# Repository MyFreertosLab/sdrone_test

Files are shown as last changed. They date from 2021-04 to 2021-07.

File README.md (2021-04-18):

ESP32 ESP-IDF Drone
===================

This is a Drone Test Implementation with esp-idf and esp32.
This software is under construction

```
  git clone --recursive git@github.com:MyFreertosLab/sdrone_test.git
  idf.py build
  idf.py flash
```
<h1>State of the art</h1>
<p align="left">
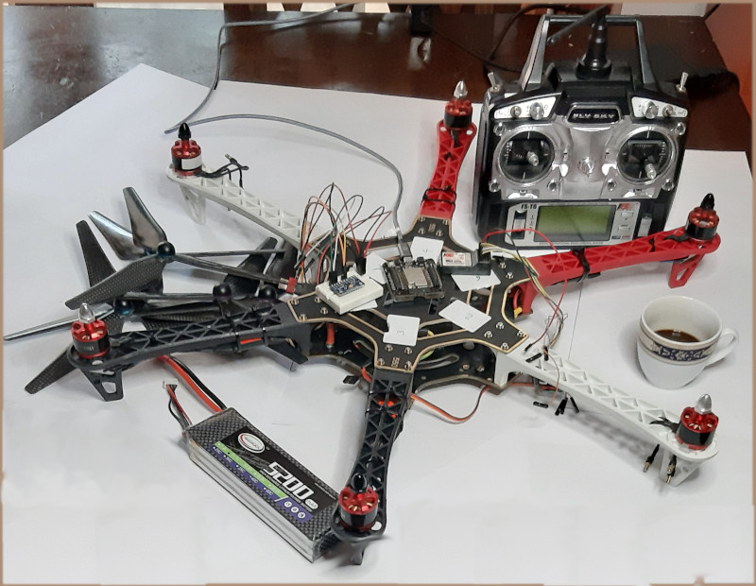
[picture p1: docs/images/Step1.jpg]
The hardware
  
  <p>Step 1: Minimal Hardware List</p>
</p>

1) The frame
2) RC TX/RX
3) PPM Encoder
4) IMU (mpu9250) with at least accelerometer and gyroscope
5) Battery
6) Esc (30Ah)
7) Motors
8) Propellers
9) The Board (a simple ESP32 board)
10) Cup of coffee

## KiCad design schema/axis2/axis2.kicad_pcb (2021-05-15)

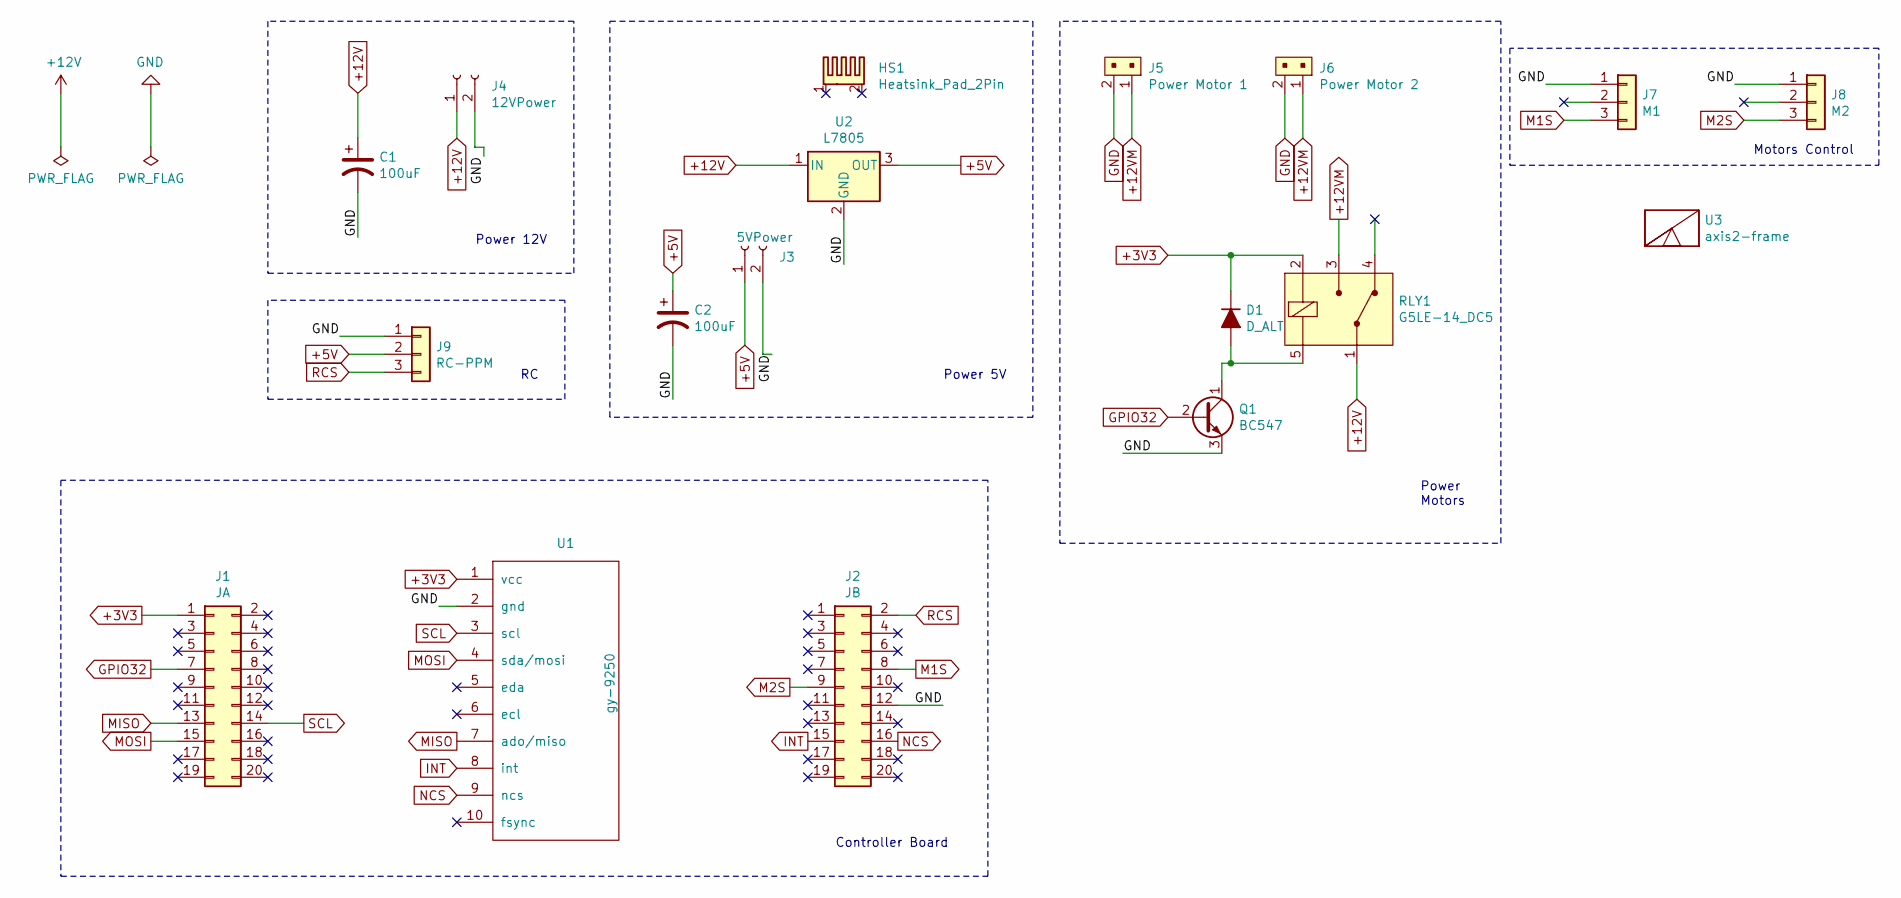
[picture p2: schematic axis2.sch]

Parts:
C1, C2: 100uF; CP_Radial_D5.0mm_P2.50mm
D1: D_ALT; D_DO-34_SOD68_P7.62mm_Horizontal
HS1: Heatsink_Pad_2Pin; Heatsink_Stonecold_HS-132_32x14mm_2xFixation1.5mm
J1: JA; PinSocket_2x10_P2.54mm_Vertical
J2: JB; PinSocket_2x10_P2.54mm_Vertical
J3: 5VPower; JST_XH_B2B-XH-AM_1x02_P2.50mm_Vertical
J4: 12VPower; BarrelJack_Wuerth_6941xx301002
J5: Power Motor 1; Deans; MPN 22-23-2021; Digi-Key_PN WM4200-ND
J6: Power Motor 2; Deans; MPN 22-23-2021; Digi-Key_PN WM4200-ND
J7: M1; PinHeader_1x03_P2.54mm_Horizontal
J8: M2; PinHeader_1x03_P2.54mm_Horizontal
J9: RC-PPM; PinHeader_1x03_P2.54mm_Horizontal
Q1: BC547; TO-92
RLY1: G5LE-14_DC5; Relay_SPDT_Omron-G5LE-1; MPN G5LE-14 DC5; Digi-Key_PN Z1011-ND
U1: gy-9250
U2: L7805; TO-220-3_Vertical
U3: axis2-frame; axis2-footprint

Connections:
+3V3: D1.1 (K), J1.1, RLY1.2 (COIL), U1.1 (vcc)
+5V: C2.1, J3.1, J9.2, U2.3 (OUT)
+12V: C1.1, J4.1, RLY1.1 (COM), U2.1 (IN)
+12VM: J5.1, J6.1, RLY1.3 (NO)
GND: C1.2, C2.2, J2.12, J3.2, J4.2, J5.2, J6.2, J7.1, J8.1, J9.1, Q1.3 (E), U1.2 (gnd), U2.2 (GND)
GPIO32: J1.7, Q1.2 (B)
INT: J2.15, U1.8 (int)
M1S: J2.8, J7.3
M2S: J2.9, J8.3
MISO: J1.13, U1.7 (ado/miso)
MOSI: J1.15, U1.4 (sda/mosi)
NCS: J2.16, U1.9 (ncs)
unnamed: D1.2 (A), Q1.1 (C), RLY1.5 (COIL)
RCS: J2.2, J9.3
SCL: J1.14, U1.3 (scl)

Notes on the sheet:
Power Motors
Power 12V
Power 5V
Controller Board
Motors Control

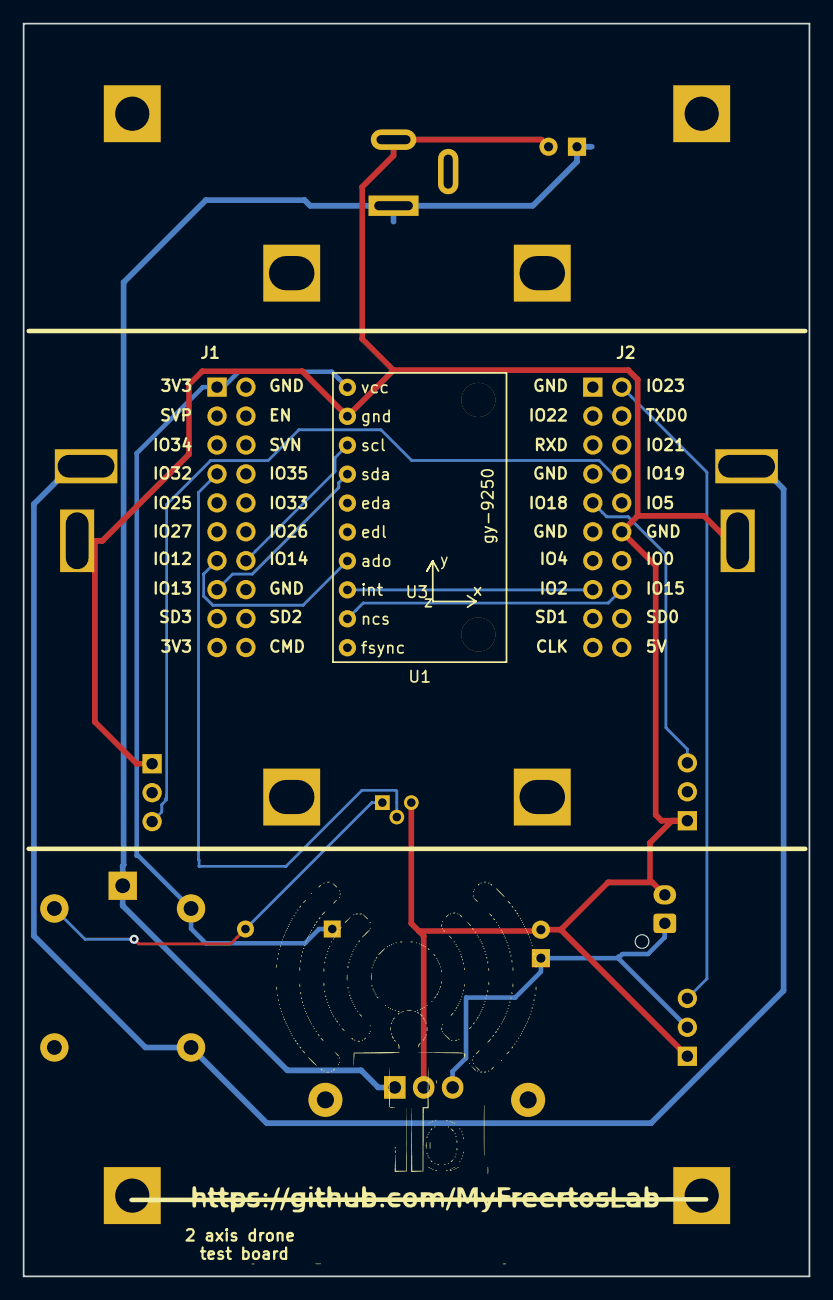
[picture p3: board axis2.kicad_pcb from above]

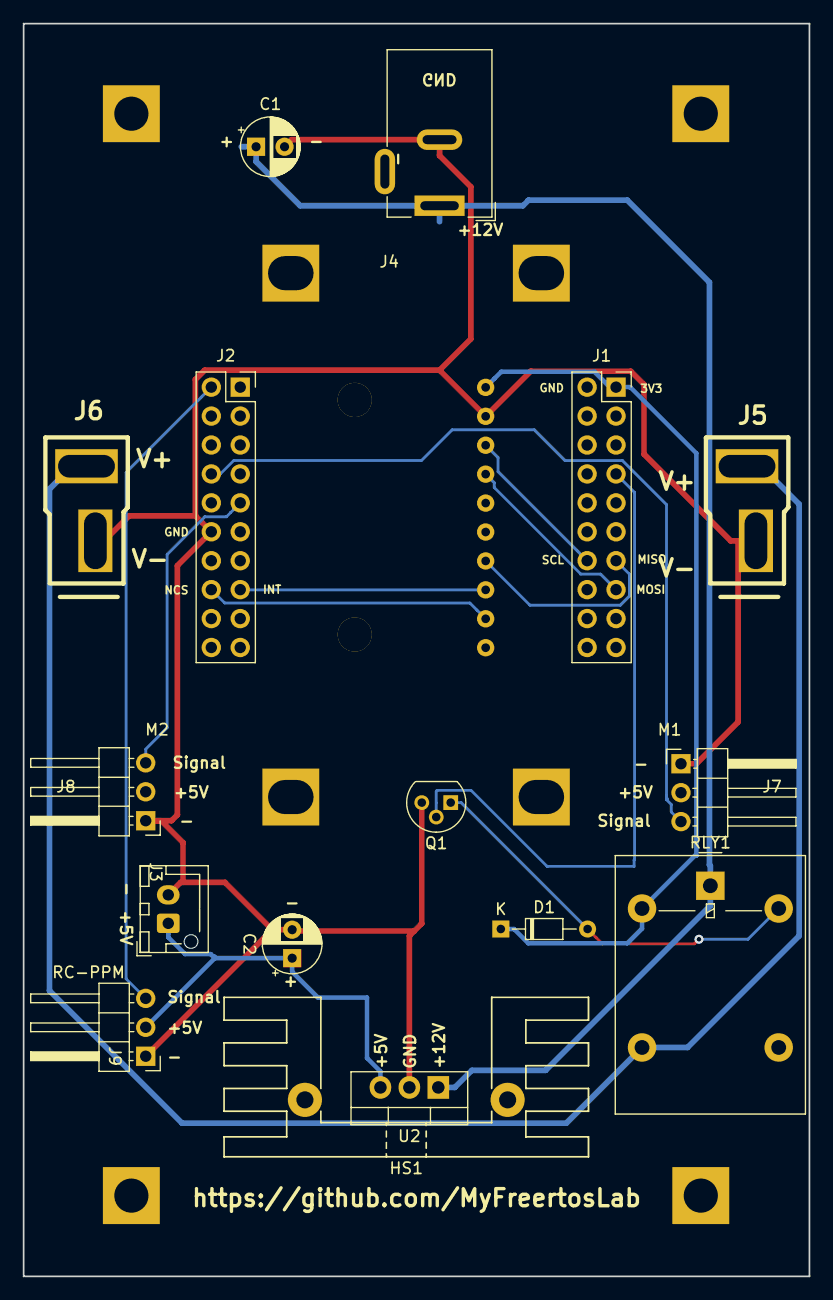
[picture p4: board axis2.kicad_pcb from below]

Board: 2 copper layers, 69.0 x 110.0 mm, 18 parts (16 on the bottom side), 15 nets.

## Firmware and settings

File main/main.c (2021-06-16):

#include "freertos/FreeRTOS.h"
#include "freertos/task.h"
#include <esp_system.h>
#include <nvs_flash.h>
#include <nvs.h>
#include <driver/i2c.h>
#include <sdrone_controller_task.h>

static sdrone_state_t sdrone_state;
static sdrone_state_handle_t sdrone_state_handle = &sdrone_state;
static TaskHandle_t controller_task_handle;
static TaskHandle_t motors_task_handle;
static TaskHandle_t rc_task_handle;
static TaskHandle_t imu_task_handle;

static esp_err_t my_i2c_init(int i2c_master_port) {
	i2c_config_t conf = {
	    .mode = I2C_MODE_MASTER,
	    .sda_io_num = GPIO_NUM_4,         // select GPIO specific to your project
	    .sda_pullup_en = GPIO_PULLUP_ENABLE,
	    .scl_io_num = GPIO_NUM_0,         // select GPIO specific to your project
	    .scl_pullup_en = GPIO_PULLUP_ENABLE,
	    .master.clk_speed = 400000,  // select frequency specific to your project
	    // .clk_flags = 0,          /*!< Optional, you can use I2C_SCLK_SRC_FLAG_* flags to choose i2c source clock here. */
	};
	ESP_ERROR_CHECK(i2c_param_config(i2c_master_port, &conf));
	ESP_ERROR_CHECK(i2c_driver_install(i2c_master_port, I2C_MODE_MASTER, 0,0,0));
	return ESP_OK;
}

esp_err_t my_nvs_init(){
    esp_err_t err = nvs_flash_init();
    if (err == ESP_ERR_NVS_NO_FREE_PAGES || err == ESP_ERR_NVS_NEW_VERSION_FOUND) {
        // NVS partition was truncated and needs to be erased
        // Retry nvs_flash_init
        ESP_ERROR_CHECK(nvs_flash_erase());
        err = nvs_flash_init();
    }
	return err;
}

void app_main(void)
{

	/*
	 * TODO: define component for hw initialization
	 */
	ESP_ERROR_CHECK(my_nvs_init());
	ESP_ERROR_CHECK(my_i2c_init(1));

	// init controller (this must be the first)
    xTaskCreate(sdrone_controller_task, "sdrone_controller_task", 4096, sdrone_state_handle, 8, &controller_task_handle);

    // init actuators
    xTaskCreate(sdrone_motors_task, "sdrone_motors_task", 4096, &(sdrone_state_handle->motors_state), 9, &motors_task_handle);

    // init sensors
    xTaskCreate(sdrone_rc_task, "sdrone_rc_task", 2048, &(sdrone_state_handle->rc_state), 5, &rc_task_handle);
    xTaskCreate(sdrone_imu_task, "sdrone_imu_task", 4096, &(sdrone_state_handle->imu_state), 10, &imu_task_handle);

    vTaskDelay(pdMS_TO_TICKS(100));

    sdrone_state_handle->motors_state.controller_task_handle = controller_task_handle;
    sdrone_state_handle->motors_state.driver_id = (uint32_t)SDRONE_MOTORS_DRIVER_ID;
    sdrone_state_handle->motors_state.controller_driver_id = (uint32_t)SDRONE_CONTROLLER_DRIVER_ID;

    sdrone_state_handle->rc_state.controller_task_handle = controller_task_handle;
    sdrone_state_handle->rc_state.driver_id = (uint32_t)SDRONE_RC_DRIVER_ID;
    sdrone_state_handle->rc_state.controller_driver_id = (uint32_t)SDRONE_CONTROLLER_DRIVER_ID;

    sdrone_state_handle->imu_state.controller_task_handle = controller_task_handle;
    sdrone_state_handle->imu_state.driver_id = (uint32_t)SDRONE_IMU_DRIVER_ID;
    sdrone_state_handle->imu_state.controller_driver_id = (uint32_t)SDRONE_CONTROLLER_DRIVER_ID;

    // Send notification to Controller.
	xTaskNotify(controller_task_handle,pdPASS,eSetValueWithOverwrite);

}

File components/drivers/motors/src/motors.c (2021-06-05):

#include <string.h>
#include <freertos/FreeRTOS.h>
#include <freertos/task.h>
#include <esp_system.h>
#include <motors.h>

static mcpwm_dev_t *MCPWM[2] = {&MCPWM0, &MCPWM1};
static mcpwm_generator_t motors_pwm_generator[MOTORS_MAX_NUM] = {
		MCPWM_GEN_A, MCPWM_GEN_B, MCPWM_GEN_A, MCPWM_GEN_B, MCPWM_GEN_A, MCPWM_GEN_B,
		MCPWM_GEN_A, MCPWM_GEN_B, MCPWM_GEN_A, MCPWM_GEN_B, MCPWM_GEN_A, MCPWM_GEN_B
};

static mcpwm_timer_t motors_timers[MOTORS_MAX_NUM] = {
		MCPWM_TIMER_0, MCPWM_TIMER_0, MCPWM_TIMER_1, MCPWM_TIMER_1, MCPWM_TIMER_2, MCPWM_TIMER_2,
		MCPWM_TIMER_0, MCPWM_TIMER_0, MCPWM_TIMER_1, MCPWM_TIMER_1, MCPWM_TIMER_2, MCPWM_TIMER_2
};

float motors_get_duty_low(motors_handle_t motors_handle) {
    return motors_handle->frequency/10.;
}
float motors_get_duty_high(motors_handle_t motors_handle) {
    return 2.0*motors_get_duty_low(motors_handle);
}
uint8_t motors_get_mcpwm_motors_range(mcpwm_unit_t unit) {
	return (unit == MCPWM_UNIT_1 ? 6 : 0);
}

esp_err_t motors_init_pwm_timer(motors_handle_t motors_handle, mcpwm_unit_t unit, mcpwm_io_signals_t timer) {
	printf("motors: motors_init_pwm_timer [%d/%d]\n", unit, timer);
    mcpwm_config_t pwm_config;
    pwm_config.frequency = motors_handle->frequency;

    float duty = motors_get_duty_low(motors_handle);
    pwm_config.cmpr_a = duty;
    pwm_config.cmpr_b = duty;
    pwm_config.counter_mode = MCPWM_UP_COUNTER;
    pwm_config.duty_mode = MCPWM_DUTY_MODE_0;
    ESP_ERROR_CHECK(mcpwm_init(unit, timer, &pwm_config));
    return ESP_OK;
}

esp_err_t motors_low_duty_motor(motors_handle_t motors_handle, uint8_t motor_indx) {
	printf("motors: motors_low_duty_motor [%d]\n", motor_indx);
	ESP_ERROR_CHECK(mcpwm_set_duty(motors_handle->motor[motor_indx].mcpwm, motors_timers[motor_indx],motors_pwm_generator[motor_indx], motors_get_duty_low(motors_handle)));
	return ESP_OK;
}

esp_err_t motors_high_duty_motor(motors_handle_t motors_handle, uint8_t motor_indx) {
	printf("motors: motors_high_duty_motor [%d], timer[%d], gen[%d]\n", motor_indx, motors_timers[motor_indx],motors_pwm_generator[motor_indx]);
	ESP_ERROR_CHECK(mcpwm_set_duty(motors_handle->motor[motor_indx].mcpwm, motors_timers[motor_indx],motors_pwm_generator[motor_indx],motors_get_duty_high(motors_handle)));
	return ESP_OK;
}

esp_err_t motors_low_duty_motors(motors_handle_t motors_handle) {
	printf("motors: motors_low_duty_motors\n");
	for (uint8_t i = 0; i < MOTORS_MAX_NUM; i++) {
		if (motors_handle->motor[i].enabled) {
			ESP_ERROR_CHECK(motors_low_duty_motor(motors_handle, i));
		}
	}
	return ESP_OK;
}

esp_err_t motors_high_duty_motors(motors_handle_t motors_handle) {
	printf("motors: motors_high_duty_motors\n");
	for (uint8_t i = 0; i < MOTORS_MAX_NUM; i++) {
		if (motors_handle->motor[i].enabled) {
			ESP_ERROR_CHECK(motors_high_duty_motor(motors_handle, i));
		}
	}
	return ESP_OK;
}

esp_err_t motors_update_motors(motors_handle_t motors_handle) {
	for (uint8_t i = 0; i < MOTORS_MAX_NUM; i++) {
	  if (motors_handle->motor[i].enabled) {
		ESP_ERROR_CHECK(mcpwm_set_duty(motors_handle->motor[i].mcpwm, motors_timers[i],motors_pwm_generator[i],motors_handle->motor[i].duty_cycle));
      }
	}
	return ESP_OK;
}

esp_err_t motors_init_mcpwm_pins(motors_handle_t motors_handle, mcpwm_unit_t unit) {
    uint8_t si = motors_get_mcpwm_motors_range(unit);
    mcpwm_pin_config_t pin_config = {
        .mcpwm0a_out_num = motors_handle->motor[0+si].pin,
        .mcpwm0b_out_num = motors_handle->motor[1+si].pin,
        .mcpwm1a_out_num = motors_handle->motor[2+si].pin,
        .mcpwm1b_out_num = motors_handle->motor[3+si].pin,
        .mcpwm2a_out_num = motors_handle->motor[4+si].pin,
        .mcpwm2b_out_num = motors_handle->motor[5+si].pin,
		// TODO: Vedere se necessari
        .mcpwm_sync0_in_num  = -1,
        .mcpwm_sync1_in_num  = -1,
        .mcpwm_sync2_in_num  = -1,
        .mcpwm_fault0_in_num = -1,
        .mcpwm_fault1_in_num = -1,
        .mcpwm_fault2_in_num = -1,
        .mcpwm_cap0_in_num   = -1,
        .mcpwm_cap1_in_num   = -1,
        .mcpwm_cap2_in_num   = -1
    };
    gpio_pullup_en(motors_handle->motor[0+si].pin);
    gpio_pullup_en(motors_handle->motor[1+si].pin);
    gpio_pullup_en(motors_handle->motor[2+si].pin);
    gpio_pullup_en(motors_handle->motor[3+si].pin);
    gpio_pullup_en(motors_handle->motor[4+si].pin);
    gpio_pullup_en(motors_handle->motor[5+si].pin);

    ESP_ERROR_CHECK(mcpwm_set_pin(unit, &pin_config));
    return ESP_OK;
}
esp_err_t motors_init_mcpwm(motors_handle_t motors_handle, mcpwm_unit_t unit) {
	printf("motors: motors_init_mcpwm [%d]\n", unit);
	ESP_ERROR_CHECK(motors_init_mcpwm_pins(motors_handle, unit));
    uint8_t si = motors_get_mcpwm_motors_range(unit);

    ESP_ERROR_CHECK(motors_init_pwm_timer(motors_handle, unit, MCPWM_TIMER_0));
    ESP_ERROR_CHECK(motors_init_pwm_timer(motors_handle, unit, MCPWM_TIMER_1));
    ESP_ERROR_CHECK(motors_init_pwm_timer(motors_handle, unit, MCPWM_TIMER_2));

    // Sync timer 1 and timer 2 with timer 0
    mcpwm_sync_enable(MCPWM_UNIT_0, MCPWM_TIMER_1, 1, 0);
    mcpwm_sync_enable(MCPWM_UNIT_0, MCPWM_TIMER_2, 1, 0);
    MCPWM[MCPWM_UNIT_0]->timer[MCPWM_TIMER_0].sync.out_sel = 1;

    for(uint8_t i = 0; i < 6; i++) {
      if(motors_handle->motor[i+si].enabled) {
        motors_handle->motor[i+si].mcpwm = unit;
        motors_handle->motor[i+si].duty_cycle = mcpwm_get_duty(unit, motors_timers[i+si], motors_pwm_generator[i+si]);
      }
    }
    printf("motors::motors_init_mcpwm: END\n");
    return ESP_OK;
};
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

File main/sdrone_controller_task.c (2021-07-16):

/*
 * sdrone_controller_task.c
 *
 *  Created on: 18 mag 2021
 *      Author: andrea
 */
#include <stdio.h>
#include <stdlib.h>
#include <string.h>
#include <math.h>
#include <freertos/FreeRTOS.h>
#include <freertos/task.h>
#include <esp_system.h>
#include <sdrone_controller_task.h>
#include <sys/time.h>
#include <time.h>

#ifdef MOTORS_FRAME_HORIZONTAL_HEXACOPTER
esp_err_t sdrone_controller_horizontal_hexacopter_init(sdrone_state_handle_t sdrone_state_handle) {
	// TODO: T.B.D.
	return ESP_OK;
}
#else
#ifdef MOTORS_FRAME_TWO_HORIZONTAL_AXIS
esp_err_t sdrone_controller_two_horizontal_axis_init(
		sdrone_state_handle_t sdrone_state_handle) {
#ifdef SDRONE_MISUREMENT_MODE
	sdrone_state_handle->controller_state.misurement_state.misurement_cycle = 0;
	sdrone_state_handle->controller_state.misurement_state.state =
			SDRONE_STATE_SET_START_TARGET;
	sdrone_state_handle->controller_state.misurement_state.target_initial =
			-0.165 * 4.0;
	sdrone_state_handle->controller_state.misurement_state.target =
			sdrone_state_handle->controller_state.misurement_state.target_initial;
	sdrone_state_handle->controller_state.misurement_state.thrust = 1.8;
	sdrone_state_handle->controller_state.misurement_state.target_increment =
			0.165; // 10 deg
	sdrone_state_handle->controller_state.misurement_state.target_final = 0.165
			* 4.0 + 0.001; // 10 deg
#endif
	sdrone_state_handle->controller_state.ierr[0] = 0.0f;
	sdrone_state_handle->controller_state.ierr[1] = 0.0f;
	sdrone_state_handle->controller_state.ierr[2] = 0.0f;
	sdrone_state_handle->controller_state.ke = 0.5f; // 0.2
	sdrone_state_handle->controller_state.ki = 0.01f; //  0.05 con scalino. Ok.
	sdrone_state_handle->controller_state.kd = 1.2f; // 60.0 con scalino. Ok.
	sdrone_state_handle->controller_state.prevErr[0] = 0.0f;
	sdrone_state_handle->controller_state.prevErr[1] = 0.0f;
	sdrone_state_handle->controller_state.prevErr[2] = 0.0f;

	return ESP_OK;
}
#endif
#endif

void sdrone_controller_init(sdrone_state_handle_t sdrone_state_handle) {
	printf("sdrone_controller_init init initial state and motors\n");
	memset(sdrone_state_handle, 0, sizeof(*sdrone_state_handle));
	sdrone_state_handle->driver_id = (uint32_t) SDRONE_CONTROLLER_DRIVER_ID;
#ifdef MOTORS_FRAME_HORIZONTAL_HEXACOPTER
	printf("sdrone_controller_init initial state sdrone initialized\n");
#else
#ifdef MOTORS_FRAME_TWO_HORIZONTAL_AXIS
	ESP_ERROR_CHECK(
			sdrone_controller_two_horizontal_axis_init(sdrone_state_handle));
#endif
#endif
}

void sdrone_controller_print_data(sdrone_state_handle_t sdrone_state_handle) {
#ifdef SDRONE_MISUREMENT_MODE
	struct timeval now;
	gettimeofday(&now, NULL);
	float time = (now.tv_sec) + 1e-6*(now.tv_usec);
	printf("%5.3f, %5.3f, %5.3f, %5.3f, %5.3f, %5.3f, %5.3f, %5.3f, %5.3f, %5.3f, %5.3f, %5.3f, %5.3f, %5.3f, %5.6f\n",
			((float) sdrone_state_handle->rc_state.rc_data.data.norm[RC_ROLL]
					* SDRONE_NORM_ROLL_TO_RADIANS_FACTOR),
			sdrone_state_handle->controller_state.X[SDRONE_TETA_POS],
			sdrone_state_handle->controller_state.X[SDRONE_OMEGA_POS],
			sdrone_state_handle->controller_state.X[SDRONE_ALFA_POS],
			((float) sdrone_state_handle->rc_state.rc_data.data.norm[RC_THROTTLE]
					* SDRONE_NORM_THROTTLE_TO_ACCEL_FACTOR),
			sdrone_state_handle->motors_state.input.data.thrust[1],
			sdrone_state_handle->motors_state.input.data.thrust[0],
			sdrone_state_handle->controller_state.err[SDRONE_TETA_POS],
			sdrone_state_handle->controller_state.err[SDRONE_OMEGA_POS],
			sdrone_state_handle->controller_state.err[SDRONE_ALFA_POS],
			sdrone_state_handle->controller_state.predX[SDRONE_TETA_POS],
			sdrone_state_handle->controller_state.predX[SDRONE_OMEGA_POS],
			sdrone_state_handle->controller_state.predX[SDRONE_ALFA_POS],
			sdrone_state_handle->controller_state.derr[SDRONE_ALFA_POS],
			time
			);
	vTaskDelay(1);
#else
	//	printf("predX[%5.3f, %5.3f, %5.3f]\n",
	//			sdrone_state_handle->controller_state.predX[SDRONE_TETA_POS],
	//			sdrone_state_handle->controller_state.predX[SDRONE_OMEGA_POS],
	//			sdrone_state_handle->controller_state.predX[SDRONE_ALFA_POS]);
			printf("X[%5.3f, %5.3f, %5.3f, %5.3f, %5.3f, %5.3f]\n",
					sdrone_state_handle->motors_state.input.data.thrust[1],
					sdrone_state_handle->motors_state.input.data.thrust[0],
					sdrone_state_handle->controller_state.X[SDRONE_TETA_POS],
					sdrone_state_handle->controller_state.err[SDRONE_ALFA_POS],
					sdrone_state_handle->controller_state.ierr[SDRONE_ALFA_POS],
				sdrone_state_handle->controller_state.derr[SDRONE_ALFA_POS]
				  );
			vTaskDelay(1);
	//		printf("Y[%5.3f, %5.3f]\n", sdrone_state_handle->motors_state.input.data.thrust[1], sdrone_state_handle->motors_state.input.data.thrust[0]);
//			printf("U[%5.3f, %5.3f]\n", sdrone_state_handle->controller_state.U[SDRONE_TETA_POS], sdrone_state_handle->controller_state.U[SDRONE_THRUST_POS]);
	//		printf("E[%5.3f, %5.3f, %5.3f]\n",
	//				sdrone_state_handle->controller_state.err[SDRONE_TETA_POS],
	//				sdrone_state_handle->controller_state.err[SDRONE_OMEGA_POS],
	//				sdrone_state_handle->controller_state.err[SDRONE_ALFA_POS]);
#endif

}

#ifdef MOTORS_FRAME_HORIZONTAL_HEXACOPTER
#ifdef SDRONE_MISUREMENT_MODE
esp_err_t sdrone_controller_horizontal_hexacopter_misure(sdrone_state_handle_t sdrone_state_handle) {
	// TODO: T.B.D.
	return ESP_OK;
}
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

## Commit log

2021-04-18 Primo Commit
    [axis2-B.Cu.gbl, axis2-B.Mask.gbs, axis2-B.Paste.gbp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]
2021-04-18 Aggiunto bozza api motors
2021-04-19 Aggiunto qualche test di prova
2021-04-24 Corretto scheda e testato relay per switch on/off motori. Implementato ciclo di switch on/off motori
    [axis2-B.Cu.gbl, axis2-B.Mask.gbs, axis2-B.Paste.gbp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]
2021-04-24 Modificato scheda aggiungendo BC547.
    [axis2-B.Cu.gbl, axis2-B.Mask.gbs, axis2-B.Paste.gbp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]
2021-05-15 Corretto scheda per errato posizionamento alimentazione esp32
    [axis2.kicad_pcb, axis2.sch]
2021-05-22 Iniziato ad integrare imu ed rc
2021-05-24 Tolto media dai sample del giroscopio, inserito dati di calibrazione corretti
2021-05-24 Modificato schema per inversione relè e connettori alimentazione motori
    [axis2-B.Cu.gbl, axis2-B.Mask.gbs, axis2-B.Paste.gbp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]
2021-05-31 Collegato per prova un motore a RC e formulato conversione Throttle->Thrust (Newton) e Thrust->Duty(percentuale 52%->100%). Previsto una Dead Zone tra 52% e 60% del duty
2021-06-01 Quando RC non è collegato, il controller invia ai motori dati thrust non inizializzati. Corretto il problema, ma sono da rivedere le api delle componenti in modo che l'inizializzazione sia sempre a c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
    [sdrone_controller_task.c, sdrone_motors_task.c]
2021-06-01 - Il controller deve partire solo se riceve la notifica dail main. - Spostato l'inizializzazione del Throttle su task RC in modo che questo sia comunicato sempre nell'intervallo [0,SDRONE_RC_CHANNEL_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
2021-06-03 Completato supporto INA3221 e inserito codice di test (poi da togliere) per rilevare dati Bus e Shunt Voltage con tre motori collegati
2021-06-05 Modificato valori R e P del Kalman Filter. Corrispondono alla varianza ed all'errore iniziale in presenza di eliche
    [sdrone_controller_task.c, sdrone_motors_task.c]
2021-06-05 Inserito printf di debug per testare rpy con dati filtrati da filtro di kalman.
2021-06-05 Rimesso ciclo di programmazione ESC in startup
2021-06-08 Fixed controller for 2 propellers.
    [motors.c, motors.h, sdrone_controller_task.c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]
2021-06-12 Aggiunto bozza processo di misurazione
2021-06-13 Bozza di PID ... tutta da rivedere ...
2021-06-15 Sospeso implementazione PID. Devo rivedere i rapporti dPropellers e dAlfa
2021-06-16 Aggiunto calcolo alfa su gyro ed aggiunto errAlfa proporzionale in correzione sulla response
2021-06-18 Aggiunto fattore di reattività e Response Gain
2021-06-21 Tuning ke e fattore di proporzionalità alfa->pwm (response gain)
2021-07-14 Uscita Controller pari a 0.25 alfa, tolto response gain ed aumentato a 0.5 il fattore dell'errore su alfa. Converge più rapidamente
    [sdrone_controller_task.c]
